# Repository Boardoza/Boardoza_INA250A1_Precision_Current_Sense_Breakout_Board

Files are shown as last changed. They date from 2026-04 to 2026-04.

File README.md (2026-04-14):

# Boardoza INA250A1 High Precision Current Sense Breakout Board

The **Boardoza INA250A1** is a high-precision **current-sense breakout board** based on the **Texas Instruments INA250A1** integrated current shunt monitor. It combines a precision differential amplifier and an internal **2 mΩ shunt resistor**, enabling accurate current measurements with minimal external components.

This breakout board is suitable for both **unidirectional and bidirectional current sensing** applications. Making it ideal for **power monitoring, energy management, motor control, battery systems, and industrial applications** where accurate current measurement is critical.

## [Click here to purchase!](https://www.ozdisan.com/ureticiler/boardoza)
| Front Side | Back Side |
|:---:|:---:|
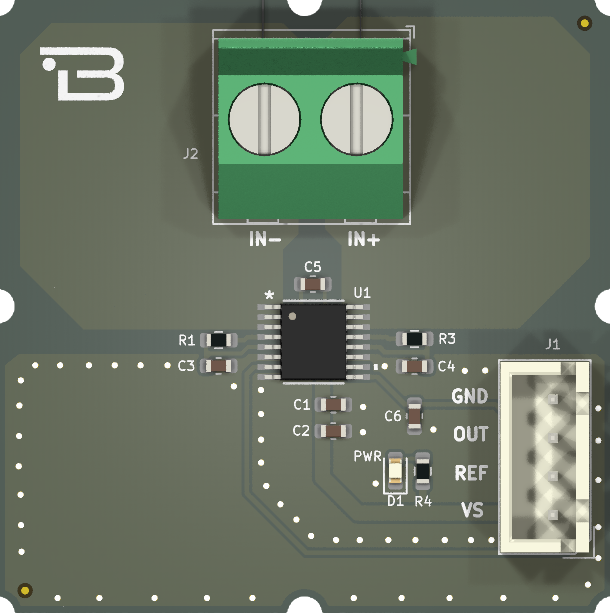
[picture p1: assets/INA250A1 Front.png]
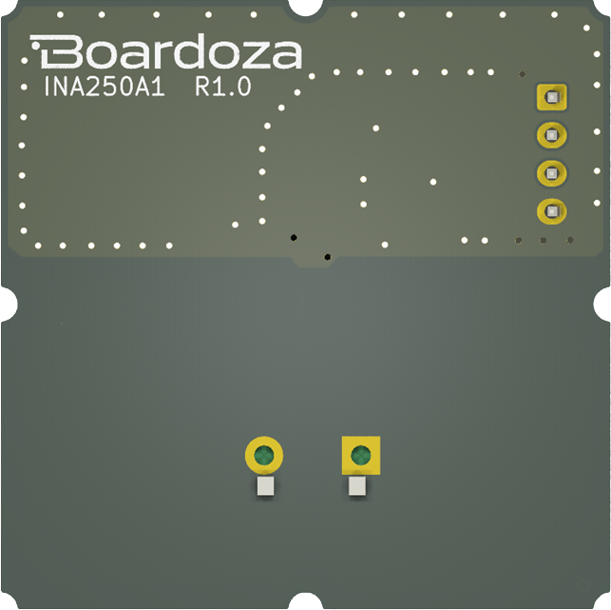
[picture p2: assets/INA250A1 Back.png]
|  |  |

---

## Key Features

- **High-Precision Current Shunt Monitor:** Enables accurate current measurement.  
- **Integrated 2 mΩ Precision Shunt Resistor:** Eliminates the need for an external shunt resistor.
- **Bidirectional Measurement Support:** Supports both unidirectional and bidirectional current measurement.
- **Wide Supply Voltage Range:** Compatible with wide supply voltage levels (**2.7 Vdc to 36 Vdc**).   
- **Analog Voltage Output:** Allows easy interfacing with ADCs and microcontrollers.
- **Low Power Consumption:** Suitable for energy-efficient applications.
- **Adjustable Reference Voltage (REF):** Enables output offset adjustment for measurement flexibility.  
- **Maximum Input Current Capability:** Supports current measurement up to **15 A (max)**.  

---

## Technical Specifications

**Model:** INA250A1  
**Manufacturer:** Boardoza  
**Manufacturer IC:** Texas Instruments  
**Functions:** Precision current sensing  
**Supply Voltage:** 2.7 V – 36 V  
**Maximum Input Current:** 15 A (Max)  
**Shunt Resistance:** 2 mΩ (internal)  
**Gain:** 200 mV/A  
**Output Type:** Analog voltage  
**Measurement Type:** Unidirectional / Bidirectional  
**Operating Temperature:** -40 °C to +125 °C  
**Board Dimensions:** 40 mm × 40 mm

---

## Board Pinout

### **( J1 ) Signal Connector**

| Pin Number | Pin Name | Description |
| :---: | :---: | --- |
| 1 | VS | Device power supply (2.7 V – 36 V) |
| 2 | REF | Reference voltage input |
| 3 | OUT | Analog output voltage |
| 4 | GND | Ground |

### **( J2 ) Current Path Connector**

| Pin Number | Pin Name | Description |
| :---: | :---: | --- |
| 1 | IN+ | Current sense input (supply side) |
| 2 | IN- | Current sense input (load side) |

---

## Board Dimensions

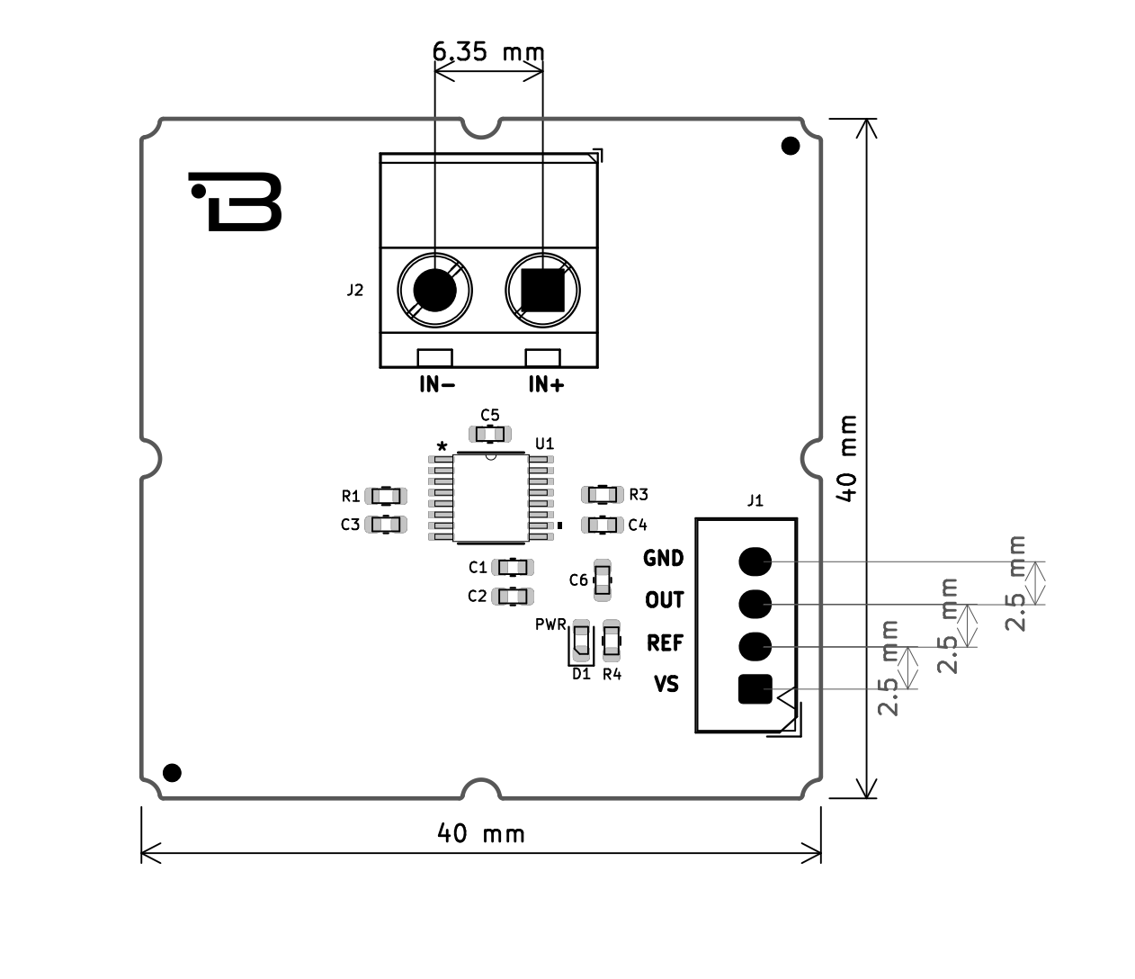
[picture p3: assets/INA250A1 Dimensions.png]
B-INA250A1-BRK Board Dimensions


---

## Step Files

[Boardoza INA250A1.step](./assets/INA250A1%20Step.step)

---

## Datasheet

[INA250 Datasheet.pdf](./assets/INA250A1%20Datasheet.pdf)

---

## Version History

- V1.0.0 – Initial Release

---

## Support

- If you have any questions or need support, please contact **<support@boardoza.com>**

---

## **License**

This repository contains both hardware and software components:

### **Hardware Design**

[][cc-by-sa]

All hardware design files are licensed under [Creative Commons Attribution-ShareAlike 4.0 International License][cc-by-sa].

[cc-by-sa]: http://creativecommons.org/licenses/by-sa/4.0/
[cc-by-sa-shield]: https://img.shields.io/badge/License-CC%20BY--SA%204.0-lightgrey.svg

### **Software/Firmware**

[][bsd]

All software and firmware are licensed under [BSD 3-Clause License][bsd].

[bsd]: https://opensource.org/licenses/BSD-3-Clause
[bsd-shield]: https://img.shields.io/badge/License-BSD%203--Clause-blue.svg

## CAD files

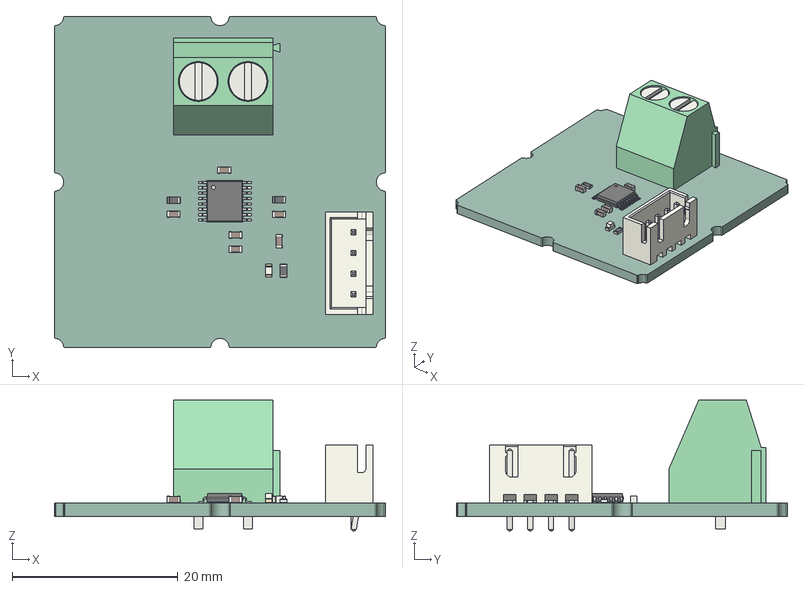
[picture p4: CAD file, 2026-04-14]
assets/INA250A1 Step.step
40.0 x 40.0 x 15.8 mm
TSSOP_16_44x5mm_P065mm
R_0603_1608Metric x 3
C_0603_1608Metric x 6
TerminalBlock_Phoenix_MKDS_15_2_1x02_P500mm_Horizontal
LED_0603_1608Metric
JST_B4B_XH_A
_autosave-B-INA250A1-BRK_PCB

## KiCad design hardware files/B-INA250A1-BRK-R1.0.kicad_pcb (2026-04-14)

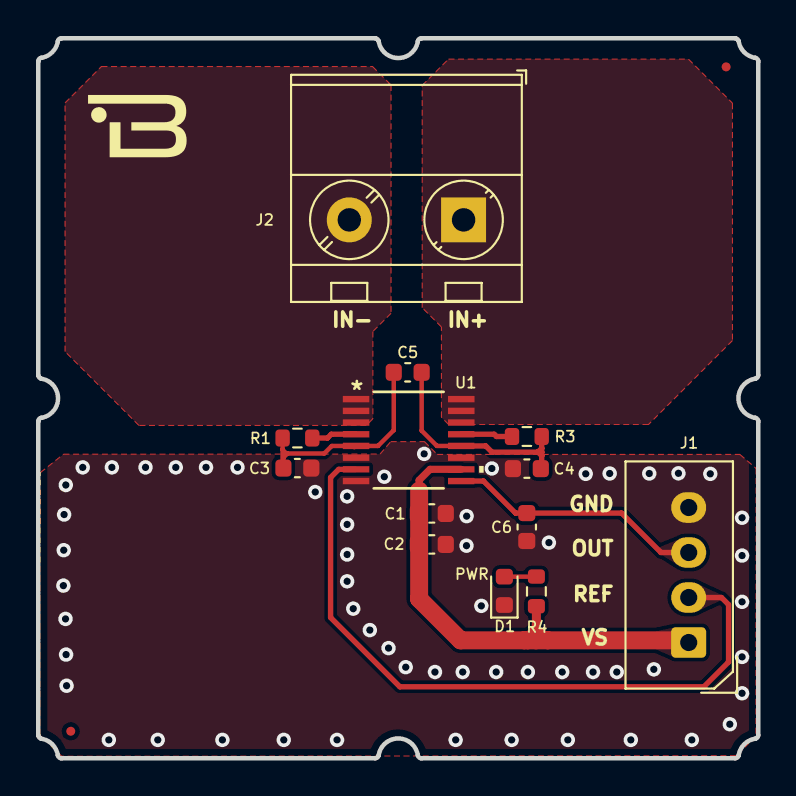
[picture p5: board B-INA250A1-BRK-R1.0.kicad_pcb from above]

Board: 2 copper layers, 40.0 x 40.0 mm, 13 parts (0 on the bottom side), 11 nets.

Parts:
C1: 0,1uF; C_0603_1608Metric
C2: 1uF; C_0603_1608Metric
C3, C4, C5: 100nF; C_0603_1608Metric
C6: 10pF; C_0603_1608Metric
D1: LED; LED_0603_1608Metric
J1: Conn_01x04; 2317-04S_1x04_P2.50mm_Vertical
J2: Screw_Terminal_01x02; TerminalBlock_MetzConnect_Type701_RT11L02HGLU_1x02_P6.35mm_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
R1, R3: 0; R_0603_1608Metric
R4: 1k; R_0603_1608Metric
U1: INA250A1PWR; PW16_TEX

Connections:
/IN+: J2.1, U1.14 (IN+), U1.15 (IN+), U1.16 (IN+)
/IN-: J2.2, U1.1 (IN-), U1.2 (IN-), U1.3 (IN-)
/OUT: C6.2, J1.3, U1.9 (OUT)
/REF: J1.2, U1.7 (REF)
/SH+: R3.1, U1.13 (SH+)
/SH-: R1.1, U1.4 (SH-)
/VIN+: C4.2, C5.2, R3.2, U1.12 (VIN+)
/VIN-: C3.1, C5.1, R1.2, U1.5 (VIN-)
/VS: C1.2, C2.2, J1.1, R4.1, U1.10 (VS)
GND: C1.1, C2.1, C3.2, C4.1, C6.1, D1.1 (K), J1.4, U1.6 (GND), U1.8 (GND), U1.11 (GND)
unnamed: D1.2 (A), R4.2

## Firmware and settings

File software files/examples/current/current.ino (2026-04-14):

#include <Arduino.h>

void setup() {
  Serial.begin(115200);
  pinMode(34, INPUT);
  analogSetAttenuation(ADC_11db); // Set attenuation to 11dB for full scale range
  analogReadResolution(12); // Set ADC resolution to 12 bits (0-4095)
}

void loop() {
  int sensorValue = analogRead(34);
  // ESP32 ADC uses 12-bit resolution (0-4095)
  // and the reference voltage is approximately 3.3V
  float current =(float) sensorValue * (3.3f / 4095.0f);
  current=current/0.2;
  Serial.print("ADC reading: ");
  Serial.print(sensorValue);
  Serial.print(" - Current Sense: ");
  Serial.print(current);
  Serial.println(" I");

  delay(100);
}

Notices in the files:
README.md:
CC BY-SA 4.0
